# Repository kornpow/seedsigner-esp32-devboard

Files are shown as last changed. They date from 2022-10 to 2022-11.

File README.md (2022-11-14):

# SeedSigner ESP32 Dev-Board
A way to quickly get more developers working on ESP32 code, without having to worry about making it on a breadboard.

# Breadboard Wiring Instructions
The schematic was based on the instructions in this repo

[Keith's wiring instructions](https://github.com/kdmukai/micropython-esp32/tree/main/docs/saola_1r_build)

# Resources
[ESP32 Datasheet](https://www.espressif.com/sites/default/files/documentation/esp32-s2_datasheet_en.pdf)

[Saola User Guide](https://docs.espressif.com/projects/esp-idf/en/latest/esp32s2/hw-reference/esp32s2/user-guide-saola-1-v1.2.html)

[3.3V Regulator Datasheet](http://cn.sg-micro.com/uploads/soft/20220506/1651835177.pdf)

[OV2640 Camera Module](https://www.uctronics.com/download/OV2640_DS.pdf)

[Waveshare 1.3in LCD Hat](https://www.waveshare.com/wiki/1.3inch_LCD_HAT)

Saola Pinout Diagram

# Power Budget
* LDO:      +800mA @ 3.3V
* OV2640:   -60mA  @ 3.3V (max)
* LCD:       -??mA @ 3.3V
* ESP32:    -310mA @ 3.3V (max)

# Pictures

## Schematic
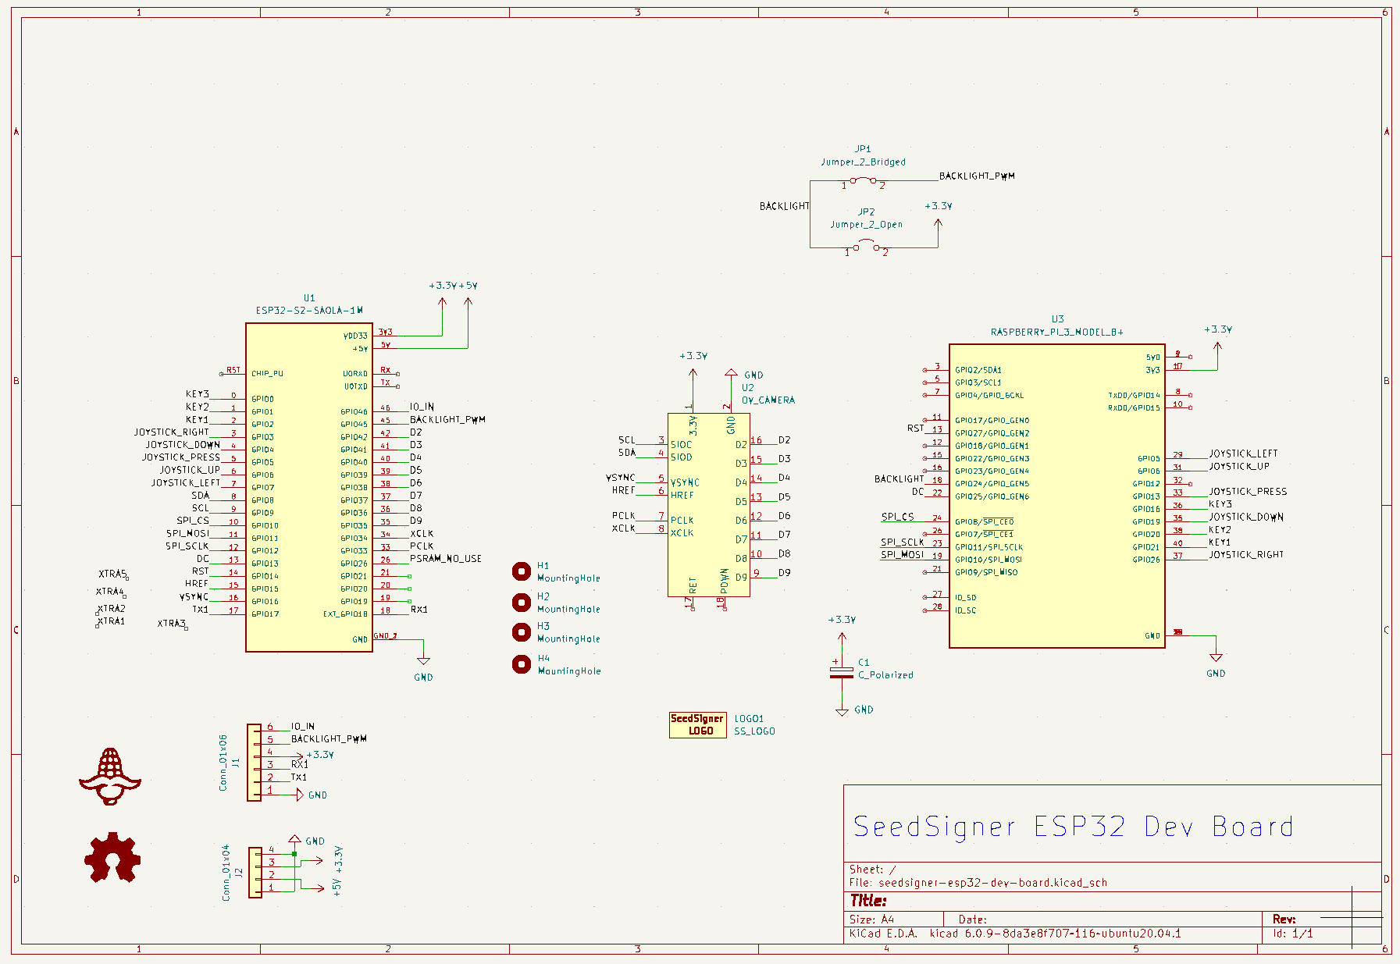
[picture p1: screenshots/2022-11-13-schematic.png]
Schematic

## PCB
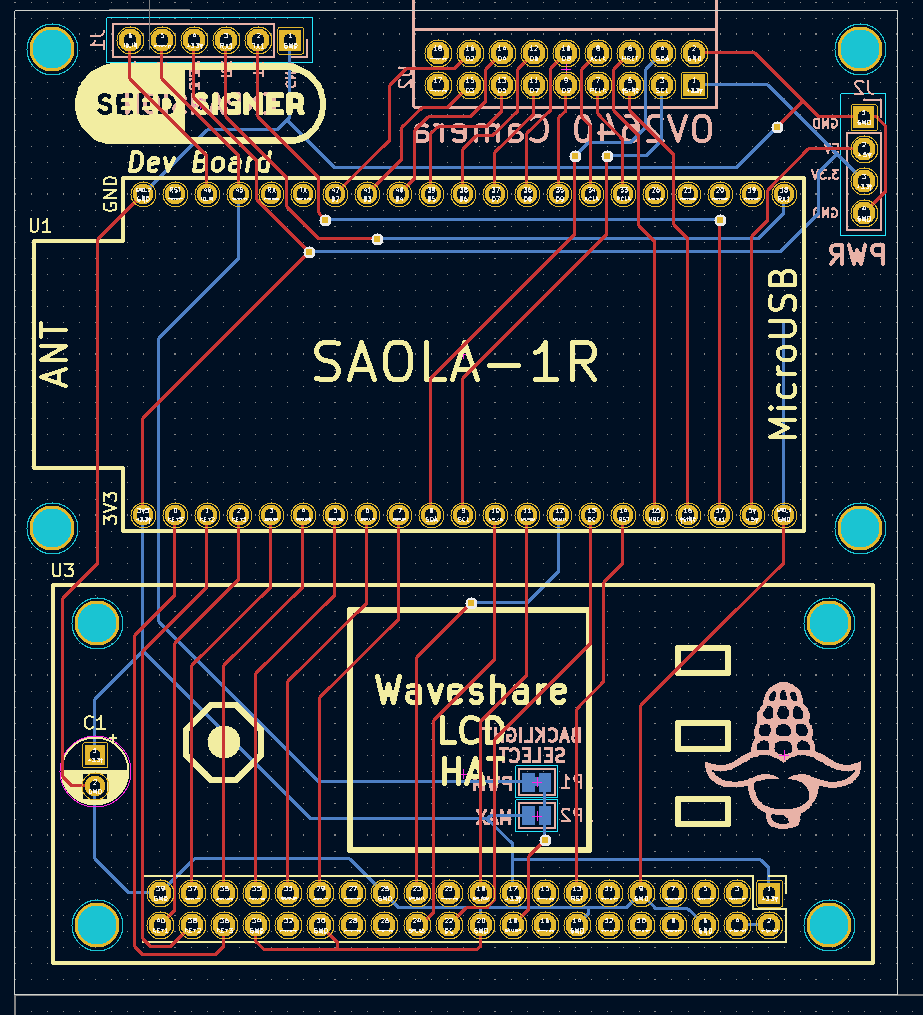
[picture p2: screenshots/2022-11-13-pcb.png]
PCB


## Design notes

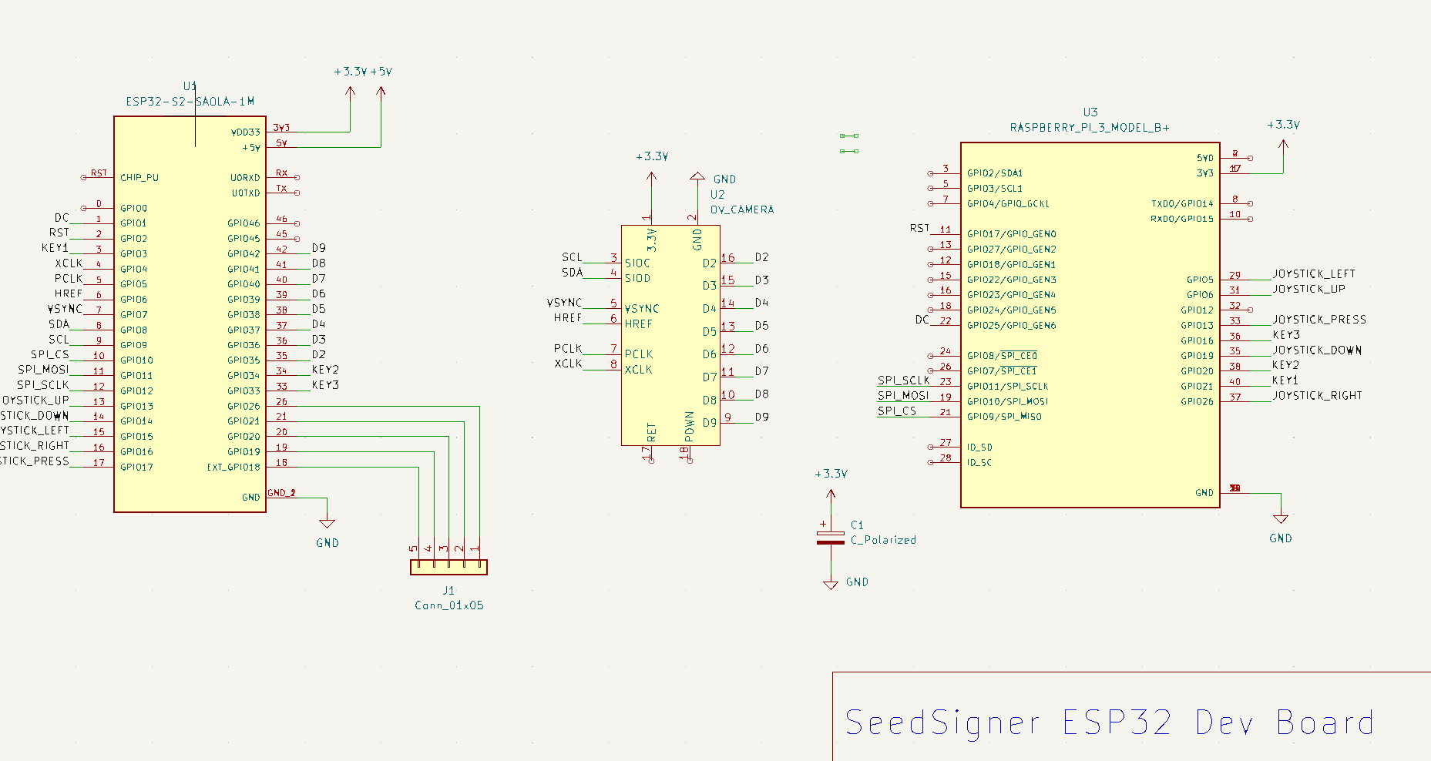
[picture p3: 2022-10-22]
screenshots/schematic-10-21-22.png

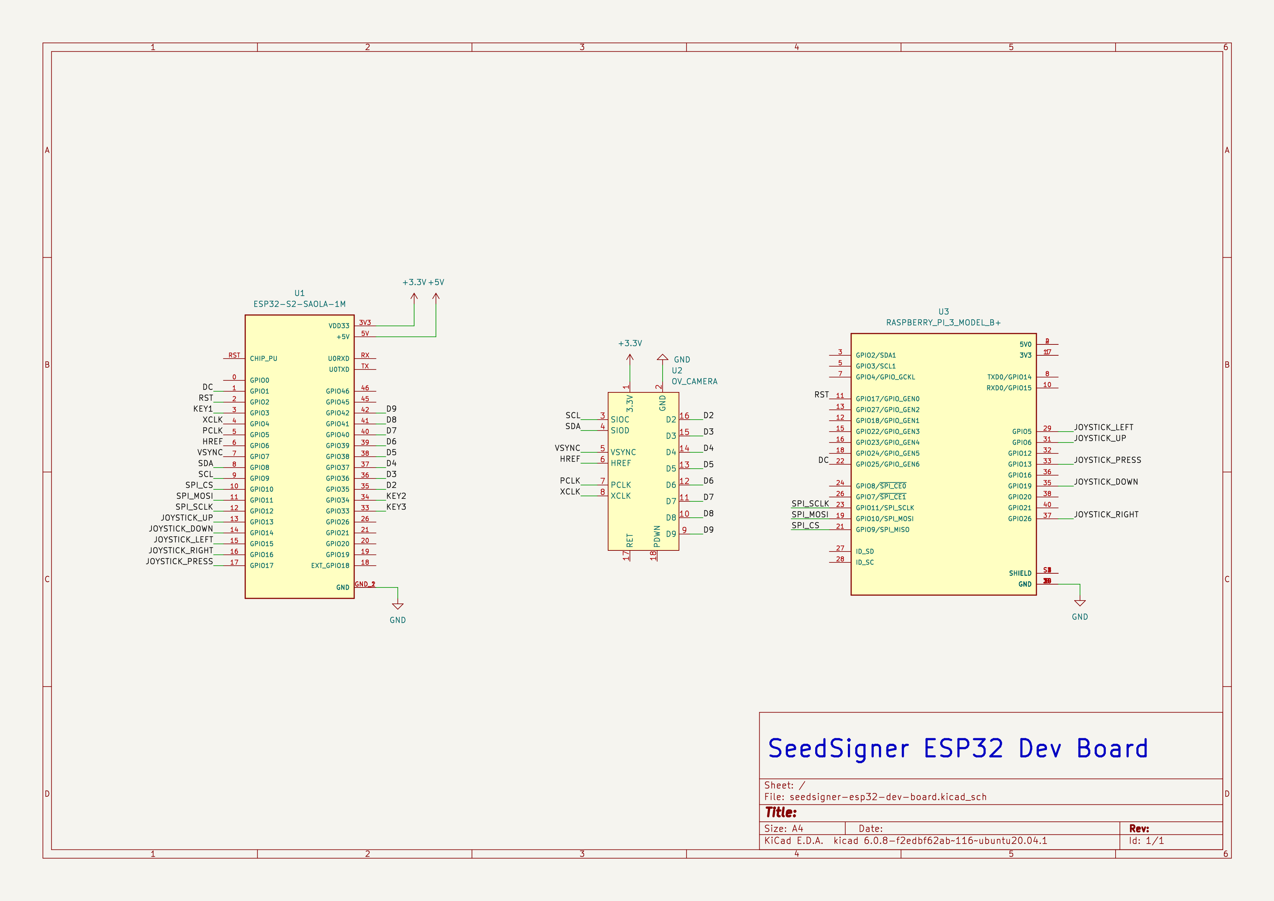
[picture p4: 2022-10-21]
screenshots/schematic-10-17-2022.png

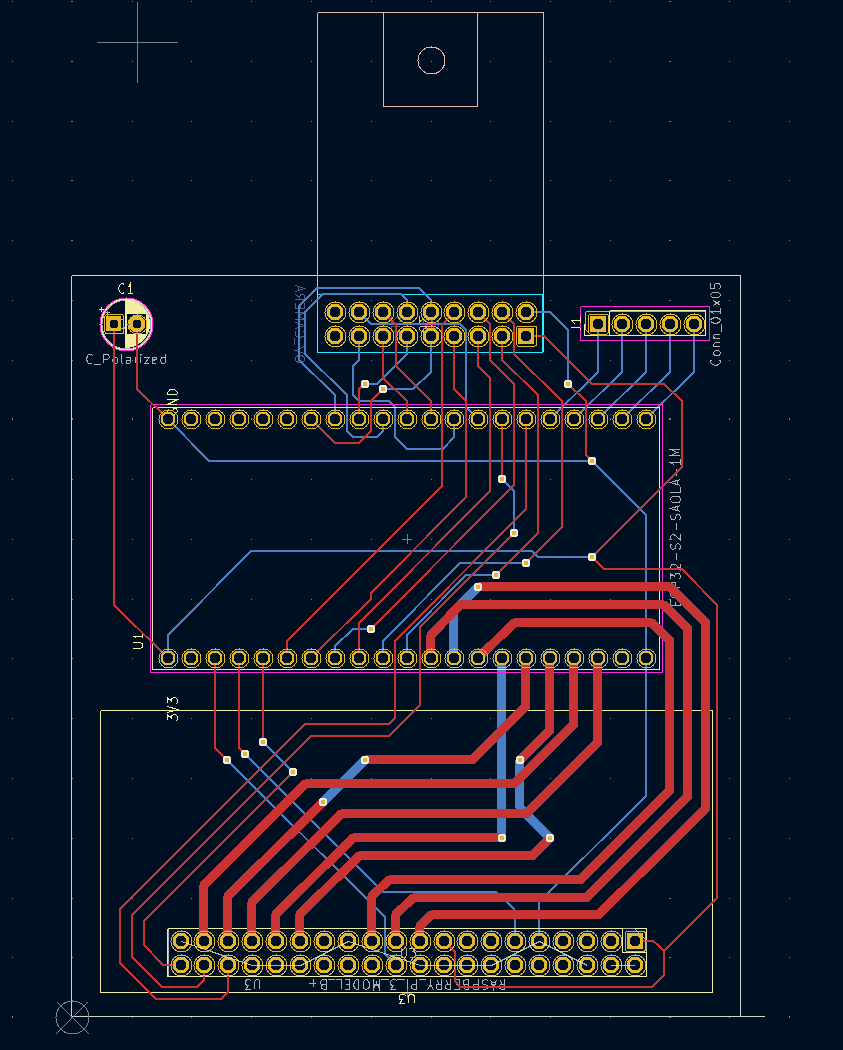
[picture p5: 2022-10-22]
screenshots/pcb-art-10-21-22.png

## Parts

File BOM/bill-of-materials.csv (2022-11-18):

DigiKey PN | MPN | Description | Price | Quantity
S9175-ND | SBH11-PBPC-D20-ST-BK | CONN HEADER VERT 40POS 2.54MM | 0.73 | 1
S7077-ND | PPTC092LFBN-RC | CONN HDR 18POS 0.1 TIN PCB | 1.09 | 1

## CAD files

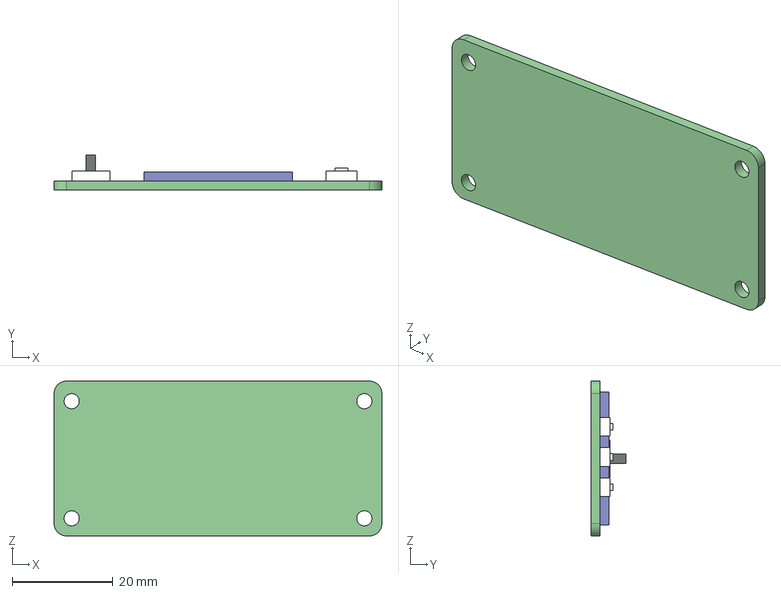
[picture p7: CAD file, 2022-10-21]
3d-models/LCD_Waveshare_240x240_1.3inch v6.step
65.0 x 7.00 x 30.7 mm

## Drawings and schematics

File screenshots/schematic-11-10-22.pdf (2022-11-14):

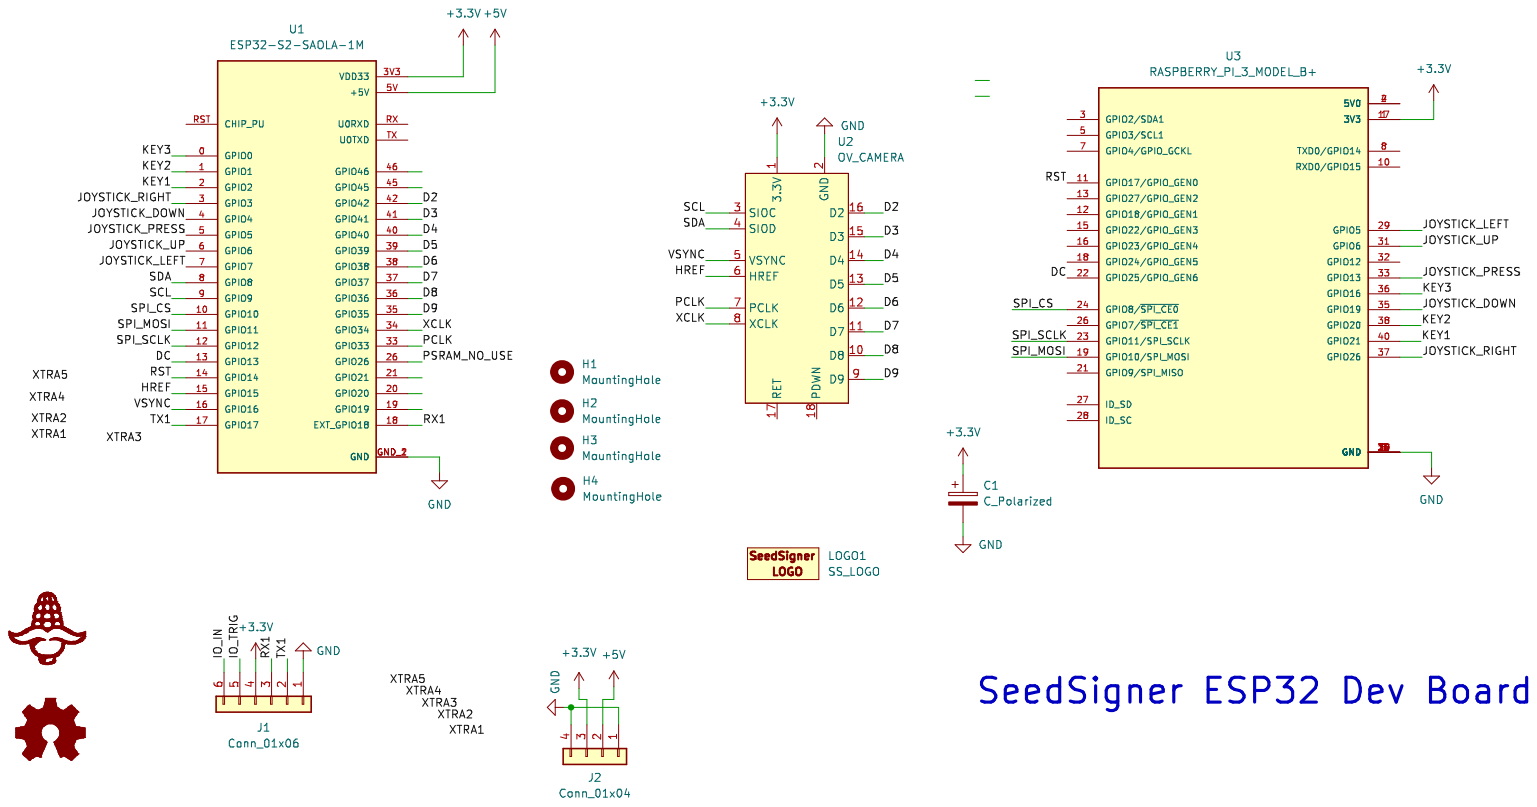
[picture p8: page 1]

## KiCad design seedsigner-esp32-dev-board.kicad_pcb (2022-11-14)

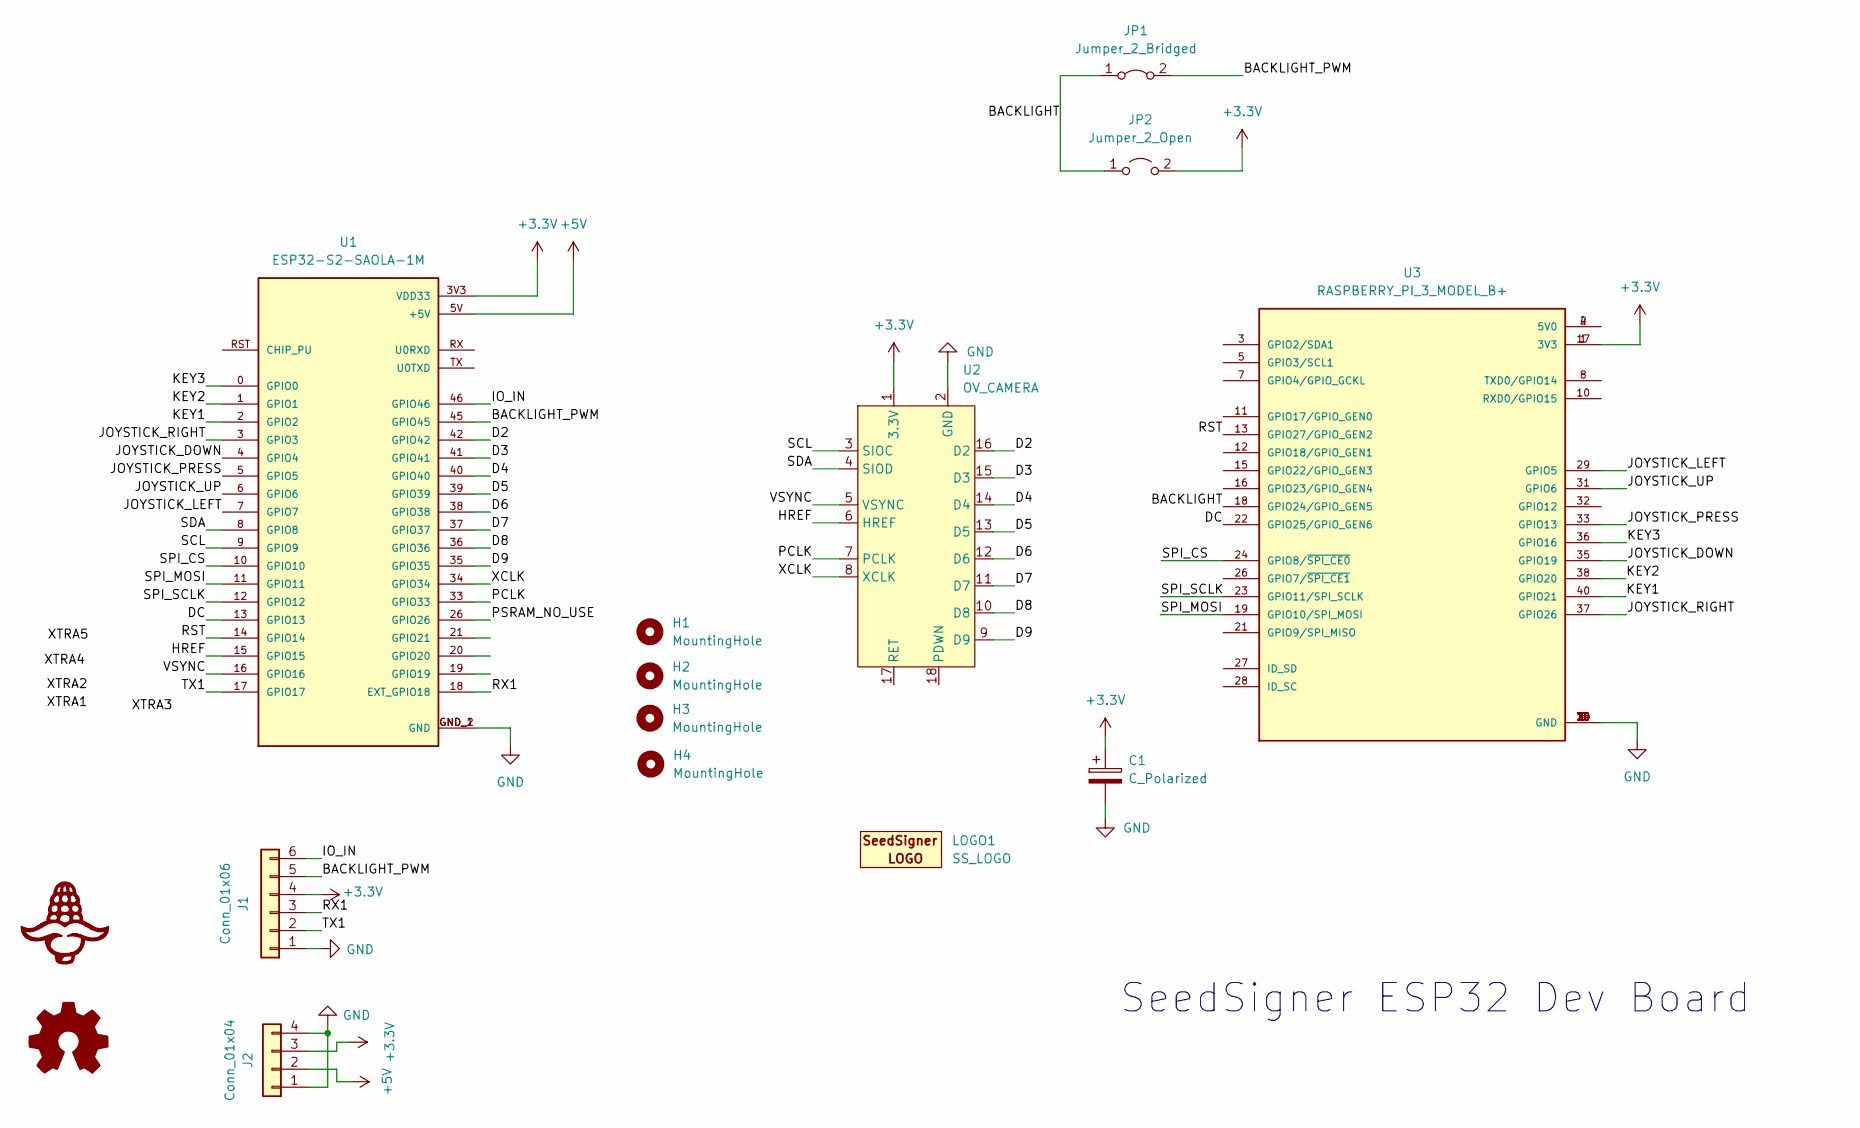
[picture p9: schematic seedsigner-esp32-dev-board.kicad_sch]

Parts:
C1: C_Polarized; CP_Radial_D5.0mm_P2.50mm
H1, H2, H3, H4: MountingHole; MOUNT_HOLE_3MM
J1: Conn_01x06; PinHeader_1x06_P2.54mm_Vertical
J2: Conn_01x04; PinHeader_1x04_P2.54mm_Vertical
JP1: Jumper_2_Bridged; SolderJumper-2_P1.3mm_Bridged_Pad1.0x1.5mm
JP2: Jumper_2_Open; SolderJumper-2_P1.3mm_Open_Pad1.0x1.5mm
LOGO1: SS_LOGO; seedsigner-logo-small
LOGO2: CORN-LOGO; corn-logo
U1: ESP32-S2-SAOLA-1M; MODULE_ESP32-S2-SAOLA-1M; PARTREV v1.2
U2: OV_CAMERA; OV_Camera
U3: RASPBERRY_PI_3_MODEL_B+; WAVESHARE_LCD_BUTTON; PARTREV 1.0

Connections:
+3.3V: C1.1, J1.4, J2.3, JP2.2 (B), U1.3V3 (VDD33), U2.1 (3.3V), U3.1 (3V3), U3.17 (3V3)
+5V: J2.2, U1.5V (+5V)
/BACKLIGHT: JP1.1 (A), JP2.1 (A), U3.18 (GPIO24/GPIO_GEN5)
/BACKLIGHT_PWM: J1.5, JP1.2 (B), U1.45 (GPIO45)
/D2: U1.42 (GPIO42), U2.16 (D2)
/D3: U1.41 (GPIO41), U2.15 (D3)
/D4: U1.40 (GPIO40), U2.14 (D4)
/D5: U1.39 (GPIO39), U2.13 (D5)
/D6: U1.38 (GPIO38), U2.12 (D6)
/D7: U1.37 (GPIO37), U2.11 (D7)
/D8: U1.36 (GPIO36), U2.10 (D8)
/D9: U1.35 (GPIO35), U2.9 (D9)
/DC: U1.13 (GPIO13), U3.22 (GPIO25/GPIO_GEN6)
/HREF: U1.15 (GPIO15), U2.6 (HREF)
/IO_IN: J1.6, U1.46 (GPIO46)
/JOYSTICK_DOWN: U1.4 (GPIO4), U3.35 (GPIO19)
/JOYSTICK_LEFT: U1.7 (GPIO7), U3.29 (GPIO5)
/JOYSTICK_PRESS: U1.5 (GPIO5), U3.33 (GPIO13)
/JOYSTICK_RIGHT: U1.3 (GPIO3), U3.37 (GPIO26)
/JOYSTICK_UP: U1.6 (GPIO6), U3.31 (GPIO6)
/KEY1: U1.2 (GPIO2), U3.40 (GPIO21)
/KEY2: U1.1 (GPIO1), U3.38 (GPIO20)
/KEY3: U1.0 (GPIO0), U3.36 (GPIO16)
/PCLK: U1.33 (GPIO33), U2.7 (PCLK)
/PSRAM_NO_USE: U1.26 (GPIO26)
/RST: U1.14 (GPIO14), U3.13 (GPIO27/GPIO_GEN2)
/RX1: J1.3, U1.18 (EXT_GPIO18)
/SCL: U1.9 (GPIO9), U2.3 (SIOC)
/SDA: U1.8 (GPIO8), U2.4 (SIOD)
/SPI_CS: U1.10 (GPIO10), U3.24 (GPIO8/~SPI_CE0)
/SPI_MOSI: U1.11 (GPIO11), U3.19 (GPIO10/SPI_MOSI)
/SPI_SCLK: U1.12 (GPIO12), U3.23 (GPIO11/SPI_SCLK)
/TX1: J1.2, U1.17 (GPIO17)
/VSYNC: U1.16 (GPIO16), U2.5 (VSYNC)
/XCLK: U1.34 (GPIO34), U2.8 (XCLK)
GND: C1.2, J1.1, J2.1, J2.4, U1.GND_1 (GND), U1.GND_2 (GND), U2.2 (GND), U3.6 (GND), U3.9 (GND), U3.14 (GND), U3.20 (GND), U3.25 (GND), U3.30 (GND), U3.34 (GND), U3.39 (GND)
unnamed: U3.2 (5V0), U3.4 (5V0)

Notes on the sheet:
SeedSigner ESP32 Dev Board

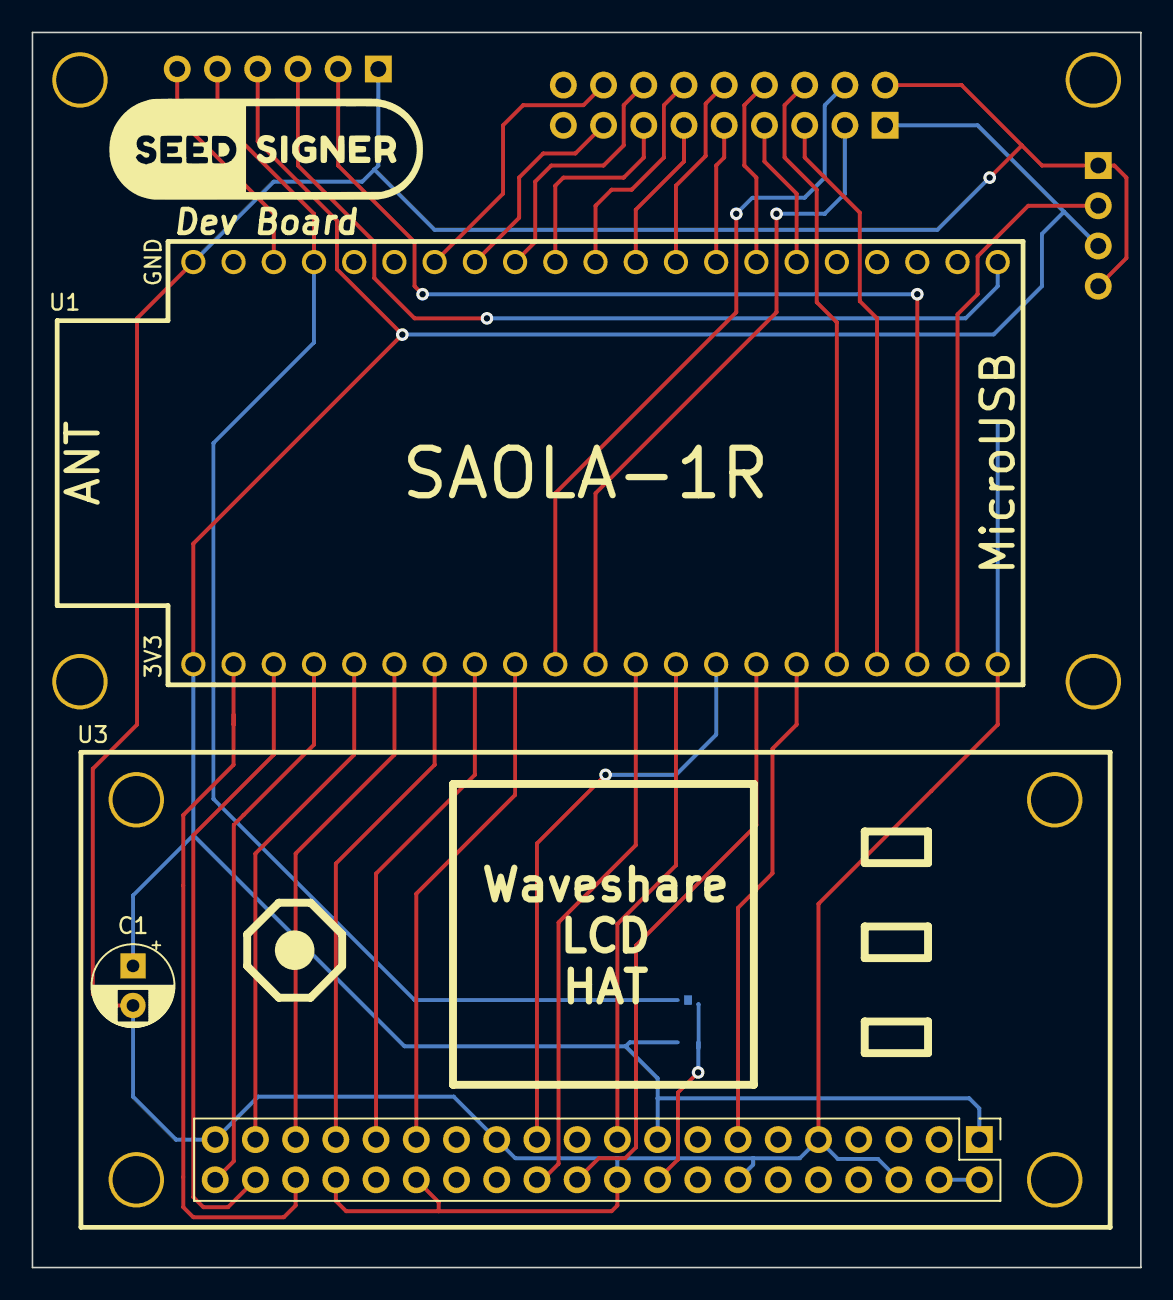
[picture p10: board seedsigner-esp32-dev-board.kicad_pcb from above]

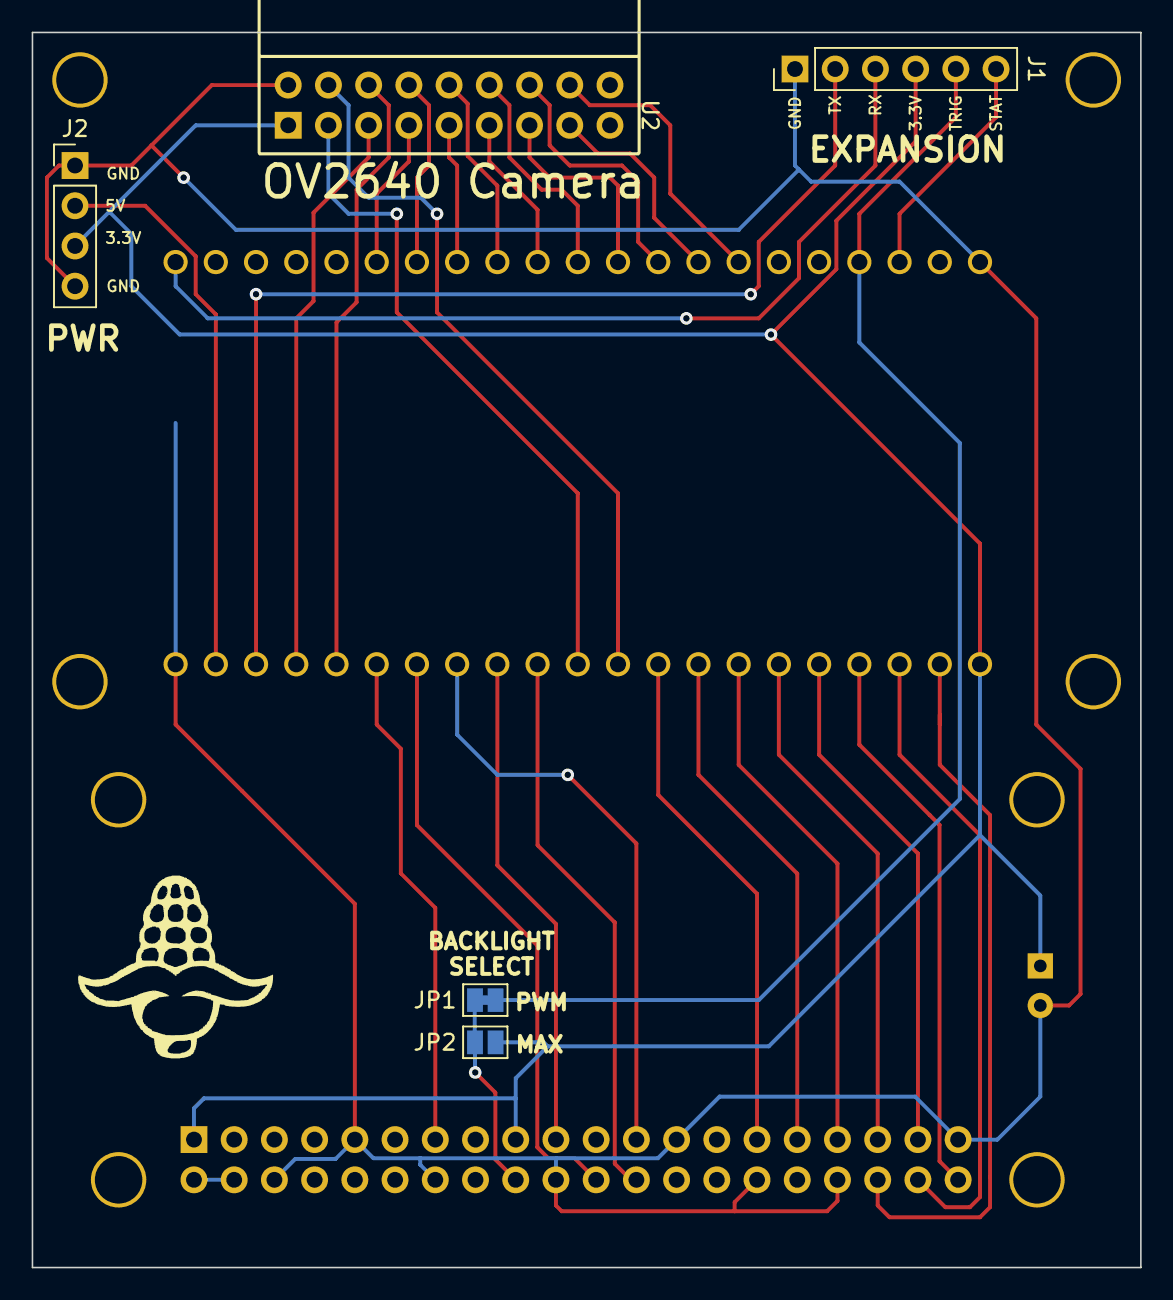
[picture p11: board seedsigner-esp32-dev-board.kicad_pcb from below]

Board: 2 copper layers, 70.0 x 78.0 mm, 14 parts (6 on the bottom side), 36 nets.

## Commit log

2022-10-21 initial commit, board is starting to be routed
    [LCD_Waveshare_240x240_1.3inch v6.step, seedsigner-esp32-dev-board.kicad_pcb, seedsigner-esp32-dev-board.kicad_sch]
2022-10-21 add symbol libraries
    [seedsigner-esp32-dev-board.kicad_pcb]
2022-10-22 update readme with links, add 3.3v to display and cap
    [seedsigner-esp32-dev-board.kicad_pcb, seedsigner-esp32-dev-board.kicad_sch]
2022-10-23 rewire all the pins to make routing cleaner
    [seedsigner-esp32-dev-board.kicad_pcb, seedsigner-esp32-dev-board.kicad_sch]
2022-10-23 fix small wiring issue, add mounting hole for lcd, add silkscreen
    [seedsigner-esp32-dev-board.kicad_pcb, seedsigner-esp32-dev-board.kicad_sch]
2022-10-26 add holes and seedsigner logo
    [seedsigner-esp32-dev-board-B_Cu.gbr, seedsigner-esp32-dev-board-B_Mask.gbr, seedsigner-esp32-dev-board-B_Paste.gbr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]
2022-10-27 cleanup and add header for DE2120
    [seedsigner-esp32-dev-board.kicad_pcb, seedsigner-esp32-dev-board.kicad_sch]
2022-10-28 small silkscreen adjustments
    [seedsigner-esp32-dev-board.kicad_pcb]
2022-11-14 add gerbers and fix RESET and PWM pin
    [esp32-dev-board-panel.kicad_pcb, esp32-dev-board-panel.kicad_sch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]
2022-11-14 update README images
    [seedsigner-esp32-dev-board.kicad_sch]
2022-11-14 final gerbers and zip
    [seedsigner-esp32-dev-board-B_Cu.gbr, seedsigner-esp32-dev-board-B_Mask.gbr, seedsigner-esp32-dev-board-B_Paste.gbr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]
2022-11-18 add bill of materials
    [bill-of-materials.csv]
